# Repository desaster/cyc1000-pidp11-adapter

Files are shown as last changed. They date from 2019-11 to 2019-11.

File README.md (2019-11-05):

# pidp11 ↔ cyc1000 adapter

This is an adapter board to connect the
[CYC1000](https://shop.trenz-electronic.de/en/Products/Trenz-Electronic/CYC1000-Intel-Cyclone-10/)
FPGA module to the
[PiDP-11, PDP-11/70 front panel replica](https://obsolescence.wixsite.com/obsolescence/pidp-11).

It is intended to be used with [PDP2011](http://pdp2011.sytse.net/), an FPGA
implementation of the PDP-11 by Sytse van Slooten.

In addition to routing the necessary pins to the panel, the board also
includes some components for use with the PDP2011:

* Micro-SDCard connector
* USB-UART bridge using the [CP2102](https://www.silabs.com/products/interface/usb-bridges/classic-usb-bridges/device.cp2102)
* Pin headers for connecting to [PMODNIC100](https://store.digilentinc.com/pmod-nic100-network-interface-controller/)

## Design considerations

* Power input from PiDP-11 header via VIN
* CYC1000 is placed underneath the adapter for clearance with the back panel
* CP2102 is bus-powered, and will not power the rest of the circuit
* The packages are chosen based on what I happen to have in my shelves

## TODO

* Actually test if the design works
* Replace CP2102 footprint with something easier to solder
* Integrate ENC424J600 to the board

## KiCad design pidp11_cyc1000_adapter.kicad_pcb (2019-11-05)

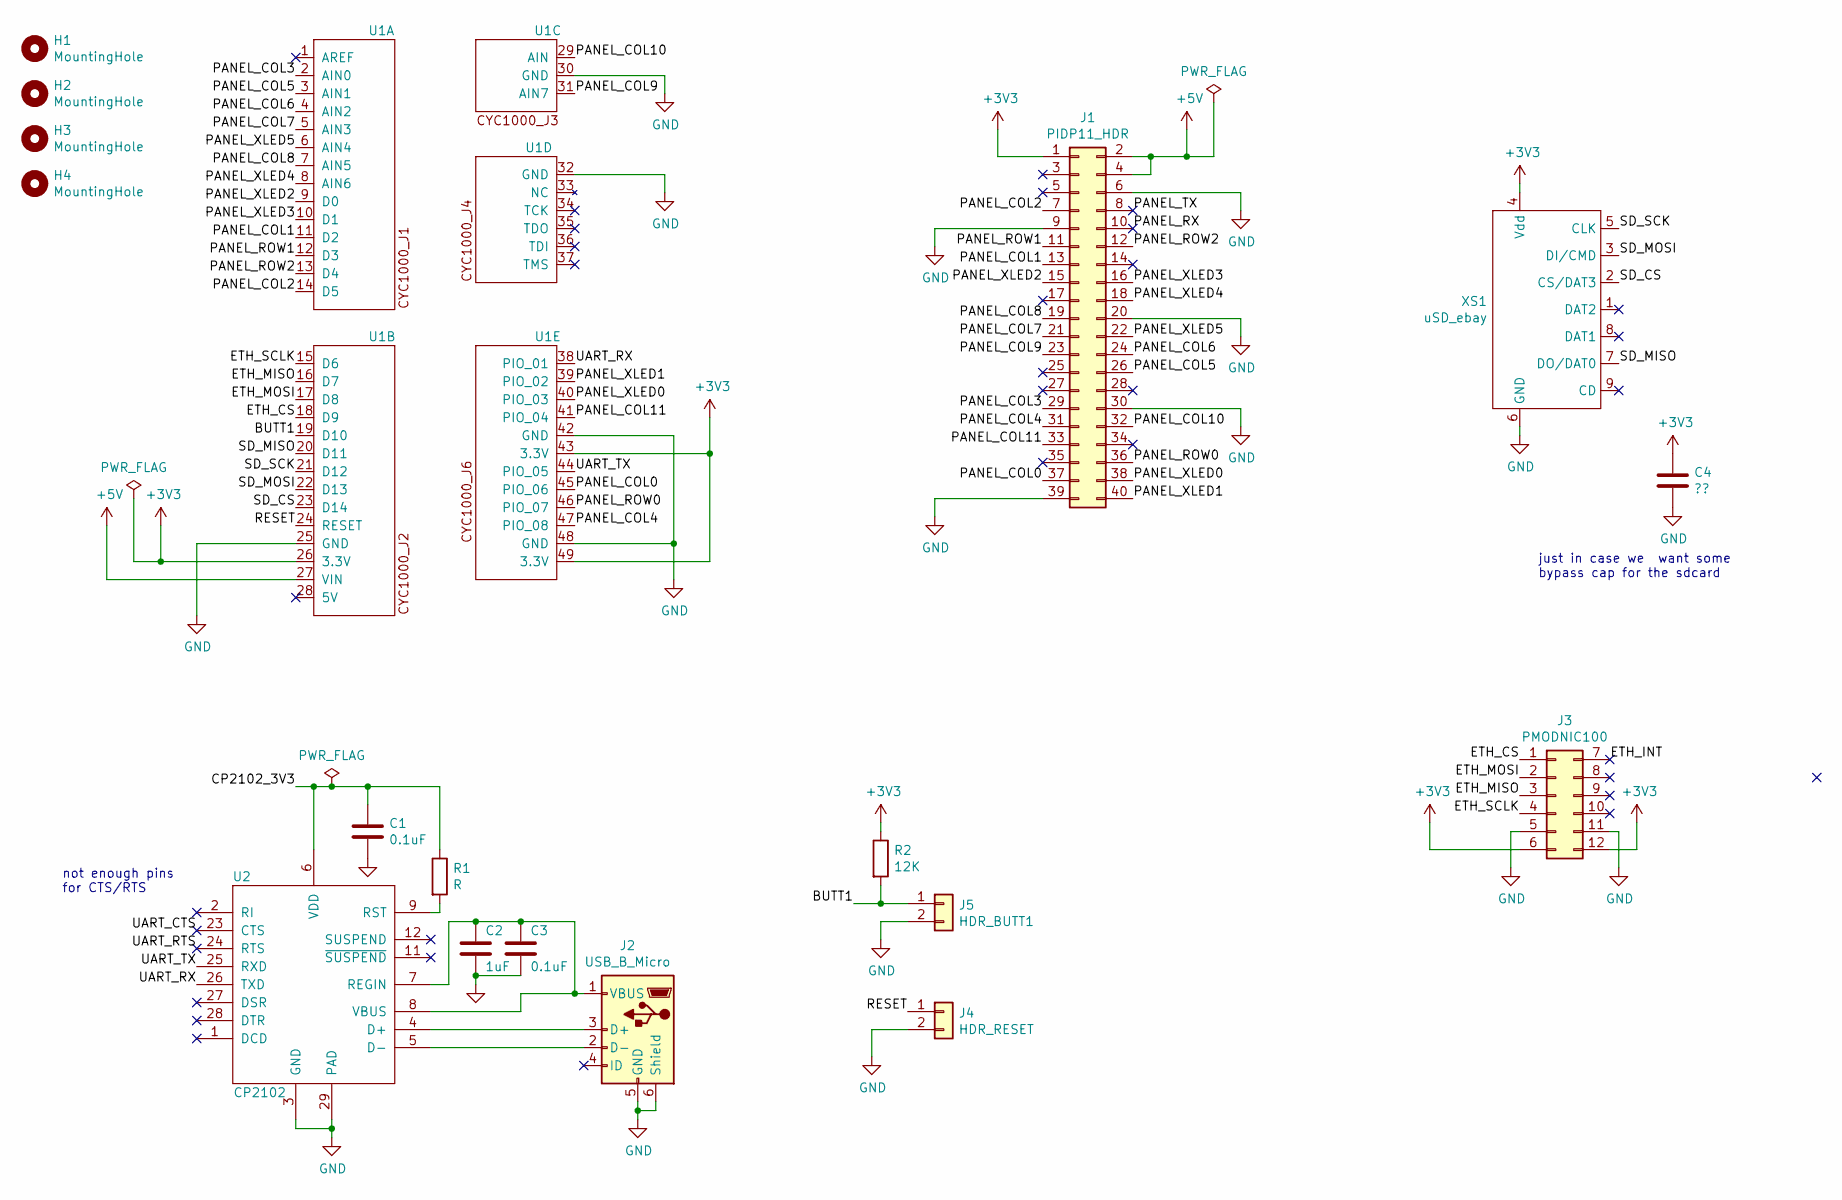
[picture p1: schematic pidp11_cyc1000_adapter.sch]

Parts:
C1: 0.1uF; C_0805_2012Metric
C2: 1uF; C_0805_2012Metric_Pad1.15x1.40mm_HandSolder
C3: 0.1uF; C_0805_2012Metric_Pad1.15x1.40mm_HandSolder
C4: ??; C_0805_2012Metric_Pad1.15x1.40mm_HandSolder
H1, H2, H3, H4: MountingHole; MountingHole_RasPI
J1: PIDP11_HDR; PinHeader_2x20_P2.54mm_Vertical
J2: USB_B_Micro; USB_Mini-B_Lumberg_2486_01_Horizontal
J3: PMODNIC100; PMOD_2x06
J4: HDR_RESET; PinHeader_1x02_P2.54mm_Horizontal
J5: HDR_BUTT1; PinHeader_1x02_P2.54mm_Horizontal
R1: R; R_0805_2012Metric_Pad1.15x1.40mm_HandSolder
R2: 12K; R_0805_2012Metric_Pad1.15x1.40mm_HandSolder
U1: CYC1000
U2: CP2102; QFN-28-1EP_5x5mm_Pitch0.5mm
XS1: uSD_ebay; Conn_uSDcard

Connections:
+3V3: C4.1, J1.1, J3.6, J3.12, R2.1, U1.26 (3.3V), U1.43 (3.3V), U1.49 (3.3V), XS1.4 (Vdd)
+5V: J1.2, J1.4, U1.27 (VIN)
/BUTT1: J5.1, R2.2, U1.19 (D10)
/CP2102_3V3: C1.1, R1.1, U2.6 (VDD)
/ETH_CS: J3.1, U1.18 (D9)
/ETH_INT: J3.7
/ETH_MISO: J3.3, U1.16 (D7)
/ETH_MOSI: J3.2, U1.17 (D8)
/ETH_SCLK: J3.4, U1.15 (D6)
/PANEL_COL0: J1.37, U1.45 (PIO_06)
/PANEL_COL1: J1.13, U1.11 (D2)
/PANEL_COL2: J1.7, U1.14 (D5)
/PANEL_COL3: J1.29, U1.2 (AIN0)
/PANEL_COL4: J1.31, U1.47 (PIO_08)
/PANEL_COL5: J1.26, U1.3 (AIN1)
/PANEL_COL6: J1.24, U1.4 (AIN2)
/PANEL_COL7: J1.21, U1.5 (AIN3)
/PANEL_COL8: J1.19, U1.7 (AIN5)
/PANEL_COL9: J1.23, U1.31 (AIN7)
/PANEL_COL10: J1.32, U1.29 (AIN)
/PANEL_COL11: J1.33, U1.41 (PIO_04)
/PANEL_ROW0: J1.36, U1.46 (PIO_07)
/PANEL_ROW1: J1.11, U1.12 (D3)
/PANEL_ROW2: J1.12, U1.13 (D4)
/PANEL_RX: J1.10
/PANEL_TX: J1.8
/PANEL_XLED0: J1.38, U1.40 (PIO_03)
/PANEL_XLED1: J1.40, U1.39 (PIO_02)
/PANEL_XLED2: J1.15, U1.9 (D0)
/PANEL_XLED3: J1.16, U1.10 (D1)
/PANEL_XLED4: J1.18, U1.8 (AIN6)
/PANEL_XLED5: J1.22, U1.6 (AIN4)
/RESET: J4.1, U1.24 (RESET)
/SD_CS: U1.23 (D14), XS1.2 (CS/DAT3)
/SD_MISO: U1.20 (D11), XS1.7 (DO/DAT0)
/SD_MOSI: U1.22 (D13), XS1.3 (DI/CMD)
/SD_SCK: U1.21 (D12), XS1.5 (CLK)
/UART_CTS: U2.23 (CTS)
/UART_RTS: U2.24 (RTS)
/UART_RX: U1.38 (PIO_01), U2.26 (TXD)
/UART_TX: U1.44 (PIO_05), U2.25 (RXD)
GND: C1.2, C2.2, C3.2, C4.2, J1.6, J1.9, J1.20, J1.30, J1.39, J2.5 (GND), J2.6 (Shield), J3.5, J3.11, J4.2, J5.2, U1.25 (GND), U1.30 (GND), U1.32 (GND), U1.42 (GND), U1.48 (GND), U2.3 (GND), U2.29 (PAD), XS1.6 (GND)
unnamed: C2.1, C3.1, J2.1 (VBUS), U2.7 (REGIN), U2.8 (VBUS)
unnamed: J2.2 (D-), U2.5 (D-)
unnamed: J2.3 (D+), U2.4 (D+)
unnamed: R1.2, U2.9 (RST)

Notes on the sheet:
just in case we want some bypass cap for the sdcard
not enough pins for CTS/RTS

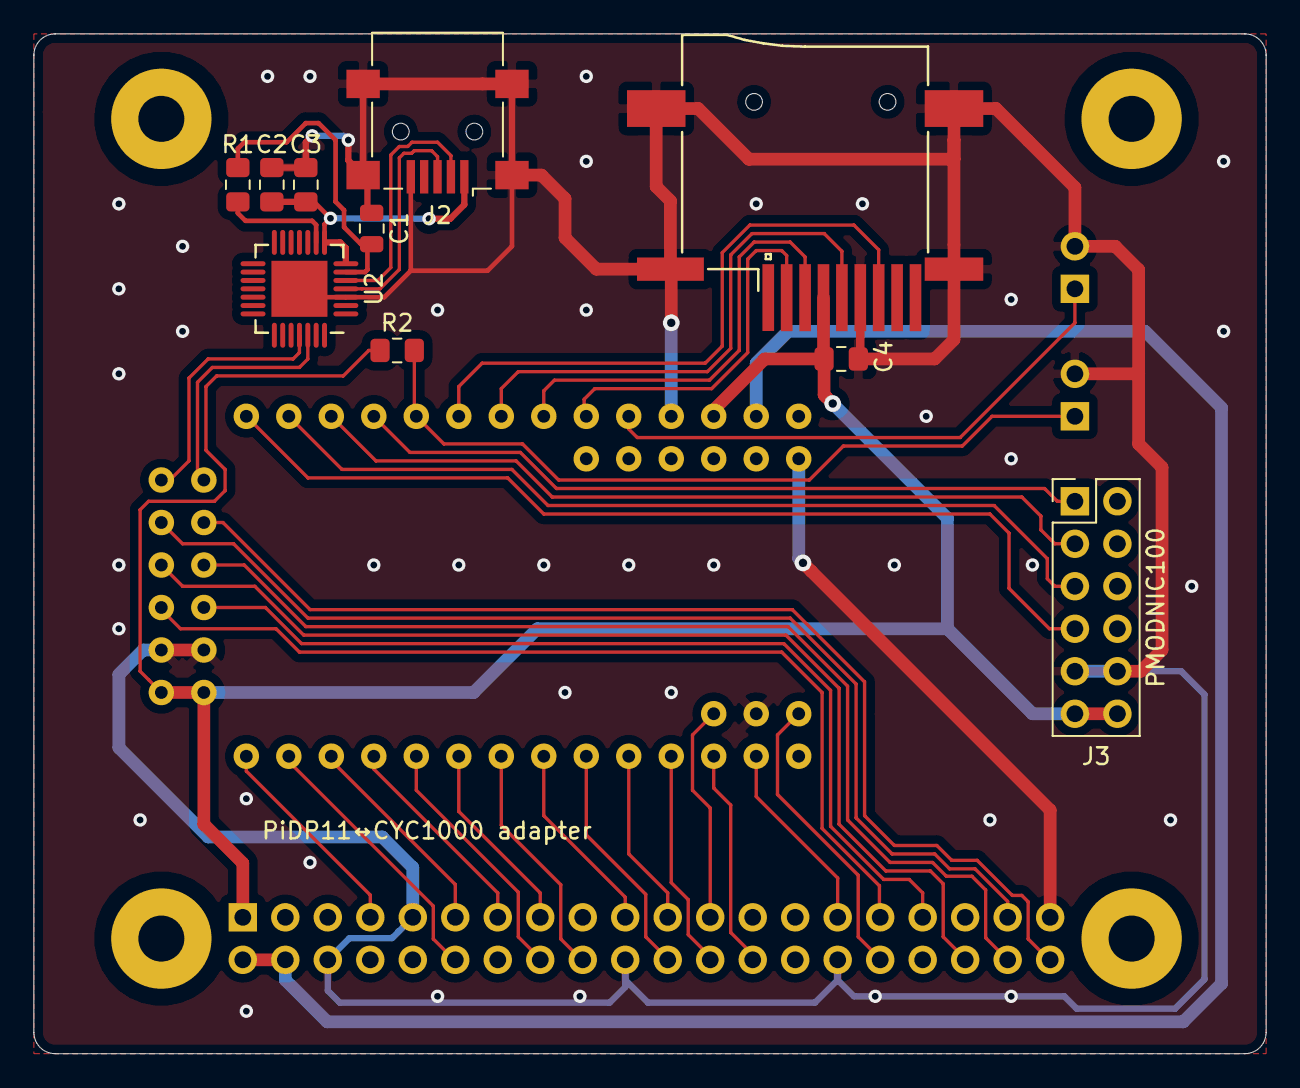
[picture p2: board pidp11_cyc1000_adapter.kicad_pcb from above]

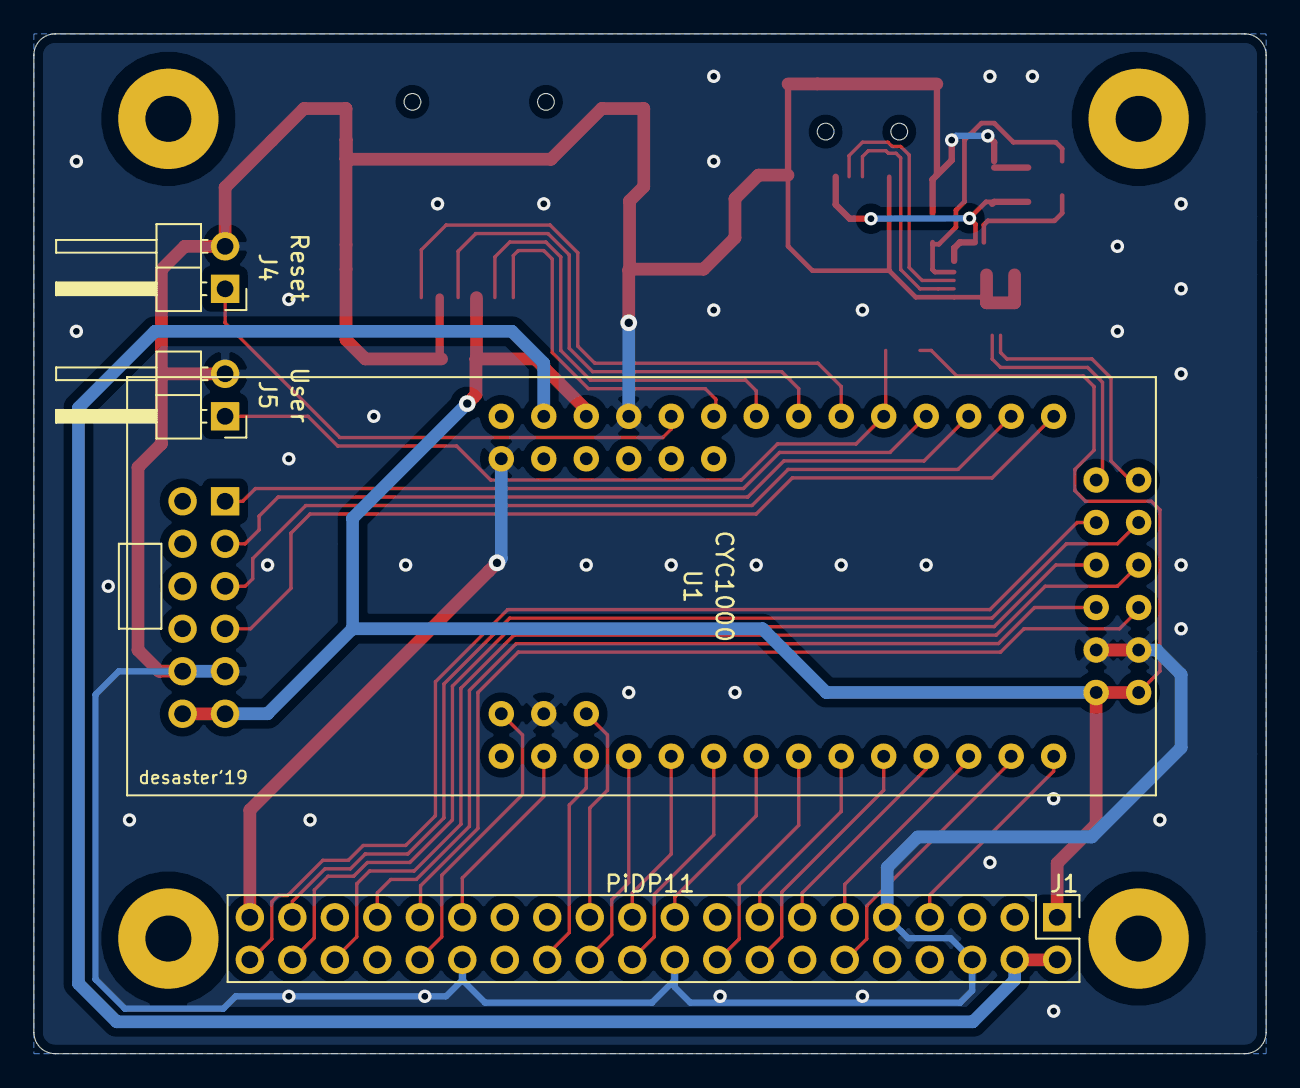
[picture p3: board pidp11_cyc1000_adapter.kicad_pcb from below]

Board: 2 copper layers, 73.7 x 61.0 mm, 18 parts (4 on the bottom side), 41 nets.

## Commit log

2019-09-11 symbol and footprint roughly done
    [pidp11_cyc1000_adapter.kicad_pcb, pidp11_cyc1000_adapter.sch]
2019-11-03 all routed
    [pidp11_cyc1000_adapter.kicad_pcb, pidp11_cyc1000_adapter.sch]
2019-11-03 add some via stitching
    [pidp11_cyc1000_adapter.kicad_pcb]
2019-11-05 final tweaks before first test run
    [pidp11_cyc1000_adapter.kicad_pcb, pidp11_cyc1000_adapter.sch]
